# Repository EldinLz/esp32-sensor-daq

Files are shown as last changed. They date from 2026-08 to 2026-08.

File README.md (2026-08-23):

# ESP32 Sensor Data Acquisition Board

A custom two-layer PCB and Arduino firmware project for collecting ambient-light, temperature, humidity, and pressure data with an ESP32-C3.

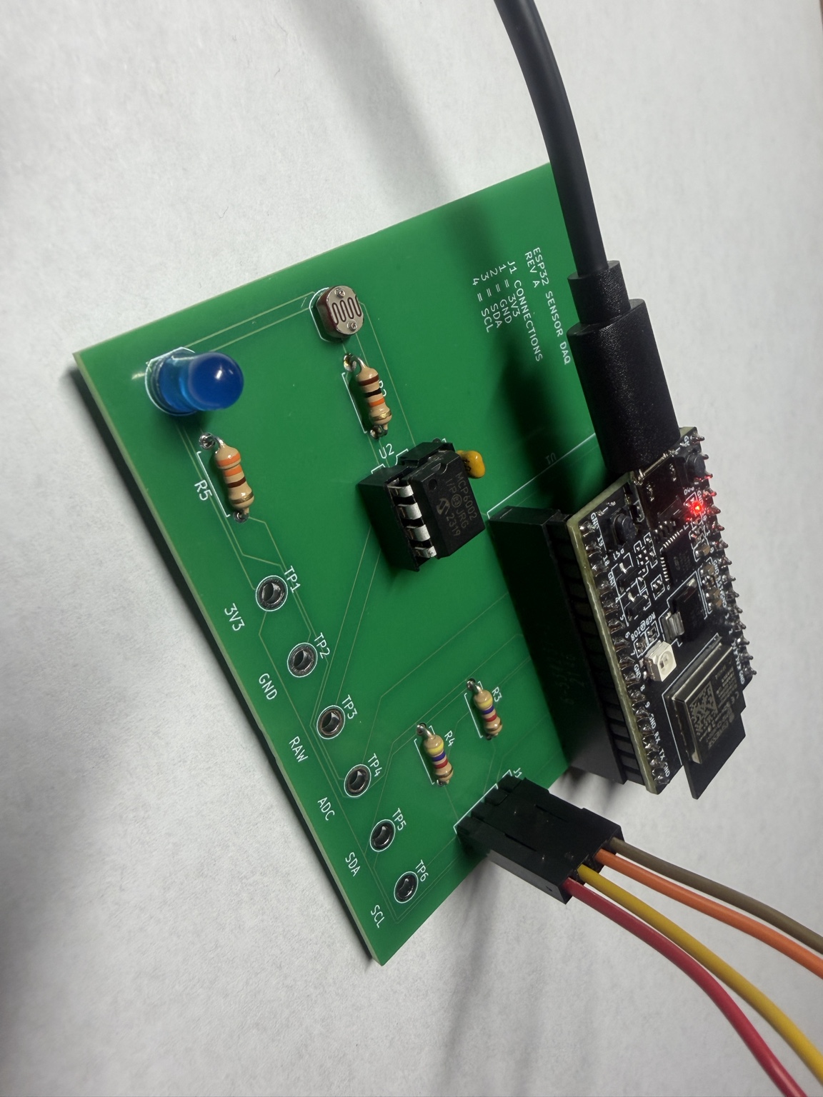
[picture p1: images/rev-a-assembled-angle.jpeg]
Assembled Rev A ESP32 sensor data-acquisition PCB


> **Project status:** Rev A was hand-assembled, programmed, and hardware-validated on 2026-08-22. The ESP32-C3 streams serial CSV data, the BME280 is detected over I2C, and the MCP6002-buffered light channel responds from covered to bright-light conditions. Long-duration logging and calibrated light measurement have not been completed.

## Overview

This project combines a custom KiCad carrier board with an ESP32-C3 DevKitM-1. A photoresistor signal is conditioned by an MCP6002 op-amp and sampled by the ESP32 ADC, while a BME280 breakout provides environmental data over I2C. Six labeled test points expose the primary power and signal nets for structured bring-up and debugging.

```mermaid
flowchart LR
    LDR["Photoresistor divider"] --> OP["MCP6002 buffer"]
    OP --> ADC["ESP32-C3 GPIO0 / ADC"]
    BME["BME280 temperature, humidity, pressure"] -->|"I2C: GPIO4 SDA, GPIO5 SCL"| ESP["ESP32-C3"]
    ADC --> ESP
    ESP --> LED["Status LED on GPIO7"]
    ESP --> USB["CSV data over USB serial"]
```

## Finished hardware

The Rev A PCB was assembled by hand with the ESP32-C3 in removable socket headers and the BME280 connected through the labeled J1 I2C header.

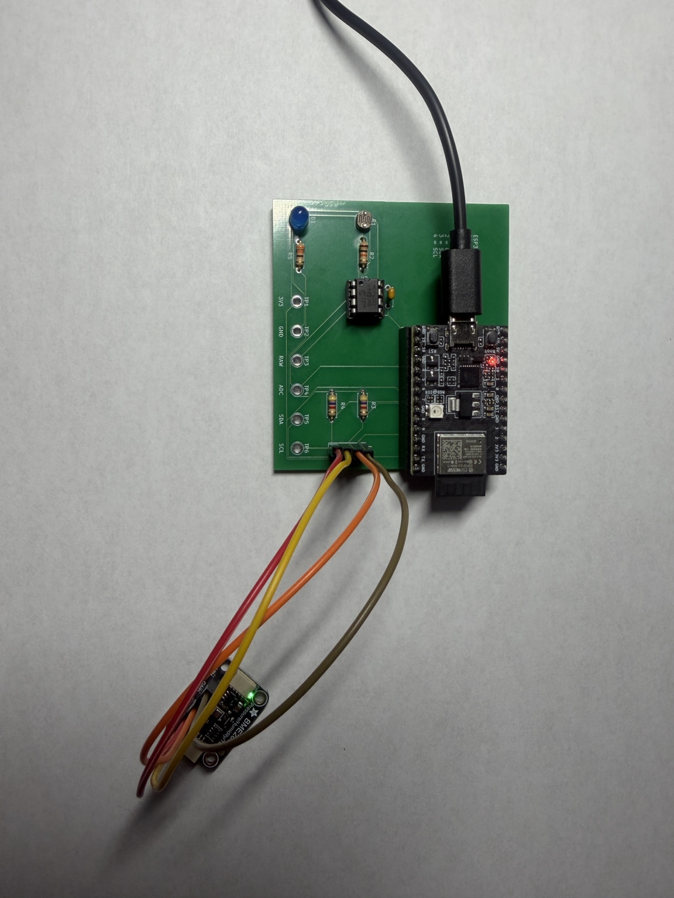
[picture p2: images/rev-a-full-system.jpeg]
Top-down view of the assembled PCB and connected BME280 breakout


## Key features

- ESP32-C3 DevKitM-1 controller on removable 1x15 sockets
- BME280 interface with 4.7 kOhm I2C pull-up resistors
- Photoresistor voltage divider buffered by an MCP6002 op-amp
- 100 nF local decoupling capacitor for the analog section
- Status LED with a 330 Ohm current-limiting resistor
- Six labeled test points: 3V3, GND, raw light signal, buffered ADC signal, SDA, and SCL
- CSV serial output suitable for logging or plotting
- Through-hole construction for accessible hand assembly and rework

## Pin map

| Function | ESP32-C3 pin | PCB test point or connector |
|---|---:|---|
| Light sensor ADC | GPIO0 | TP4 `ADC` |
| I2C SDA | GPIO4 | TP5 `SDA`, J1 pin 3 |
| I2C SCL | GPIO5 | TP6 `SCL`, J1 pin 4 |
| Status LED | GPIO7 | D1 through R5 |
| 3.3 V | 3V3 | TP1, J1 pin 1 |
| Ground | GND | TP2, J1 pin 2 |
| Raw light-divider signal | - | TP3 `RAW` |

## Firmware

The Arduino firmware:

1. Initializes the ESP32 ADC and the BME280 at address `0x77`, then tries `0x76` as a fallback.
2. Samples the buffered light-sensor signal once per second.
3. Reads temperature, humidity, and pressure when the BME280 is available.
4. Emits one CSV row per second at 115200 baud.

Measured Rev A serial output:

```text
BME280 detected
time_ms,light_raw,light_percent,temperature_C,humidity_percent,pressure_hPa
628,2058,50.3,25.70,47.22,1009.73
```

### Build environment

- Arduino IDE 2.3.10
- `esp32` board package by Espressif Systems 3.3.11
- Board target: `ESP32C3 Dev Module`
- Adafruit BME280 Library 2.3.0 and its installed dependencies

## Rev A hardware validation

These captured values demonstrate end-to-end operation; they are not calibration data.

| Check | Result | Captured evidence |
|---|---|---|
| Post-assembly power-off check | Pass | No 3V3-to-GND short was found. |
| 3.3 V operation | Pass | The assembled board powered and ran from the ESP32-C3 3.3 V rail. |
| Firmware and serial output | Pass | Firmware uploaded successfully and produced one 115200-baud CSV row per second. |
| BME280 I2C sensing | Pass | Serial Monitor reported `BME280 detected`; observed readings were about 25.2-26.0 C, 47-49% RH, and 1009.7-1009.9 hPa. |
| Light channel - covered | Pass | `light_raw` approximately 247-265; `light_percent` approximately 6.0-6.5%. |
| Light channel - room light | Pass | `light_raw` approximately 1887-2134; `light_percent` approximately 46.1-52.1%. |
| Light channel - flashlight | Pass | `light_raw` = 4095; `light_percent` = 100.0%. |
| Status LED | Pass | A brief firmware-driven activity blink was observed. |

`light_percent` is the 12-bit ADC reading normalized to full scale; it is not a calibrated lux measurement. The light tests validate the complete photoresistor-divider, MCP6002-buffer, ADC, firmware, and serial-output path, but do not independently characterize the op-amp transfer function.

See [VALIDATION.md](docs/VALIDATION.md) for the full validation record and [TEST_PLAN.md](docs/TEST_PLAN.md) for the staged bring-up procedure.

## Repository structure

```text
.
├── fabrication/  Final Gerber and drill archive used for PCB ordering
├── firmware/     Arduino sketch folder and firmware source
├── hardware/     KiCad schematic, PCB, and project files
├── images/       KiCad renders and finished Rev A build photos
└── docs/         BOM, validation record, test plan, and resume notes
```

## Design and validation status

- KiCad schematic ERC: 0 errors and 0 warnings
- KiCad PCB Editor DRC: 0 errors; one expected footprint/library mismatch warning after the ESP32 socket-pad customization
- Unrouted connections: 0
- Gerber and drill archive generated; PCB fabrication and delivery complete
- Rev A assembly, soldering, post-assembly short check, firmware upload, and serial output: complete
- BME280 I2C sensing and end-to-end light-channel response: hardware-validated

## Optional follow-on characterization

- Run and archive a one-hour serial logging test
- Measure TP3 (`RAW`) and TP4 (`ADC`) simultaneously to quantify buffer tracking
- Calibrate the light channel against a lux reference if absolute illumination is required

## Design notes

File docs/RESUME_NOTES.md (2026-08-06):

# Resume and Interview Notes

## Current truthful project summary

Designed a two-layer ESP32-C3 sensor data-acquisition PCB in KiCad, integrating a buffered photoresistor analog front end, BME280 I2C interface, status LED, decoupling, and six labeled test points. Routed and prepared fabrication files, ordered prototype PCBs, and wrote compile-verified Arduino C++ firmware that exports timestamped environmental data as CSV. Physical bring-up is pending hardware arrival and assembly.

## Resume bullet — current stage

- Designed and routed a 65.5 mm × 73.5 mm two-layer ESP32-C3 sensor data-acquisition PCB in KiCad, integrating an MCP6002-buffered light sensor, BME280 I2C interface, status LED, and six debug test points; generated production Gerbers and compile-verified Arduino C++ firmware for CSV telemetry.

## Resume bullet — use only after successful hardware validation

- Designed, assembled, and validated a custom ESP32-C3 environmental data-acquisition PCB, integrating analog light sensing and BME280 temperature/humidity/pressure telemetry; developed Arduino C++ firmware and verified power, I2C, ADC, and serial logging through a structured test-point bring-up plan.

## Interview talking points

- Placement was organized by functional blocks: analog sensing, I2C interface, status indication, and accessible test points.
- The MCP6002 buffers the photoresistor divider so the ADC sees a low-impedance signal.
- The firmware handles both common BME280 I2C addresses and continues logging light data when the BME280 is unavailable.
- Test points were designed in from the start so power, raw analog, buffered analog, SDA, and SCL can be measured directly.
- The project status is documented explicitly so compile checks are not confused with physical validation.

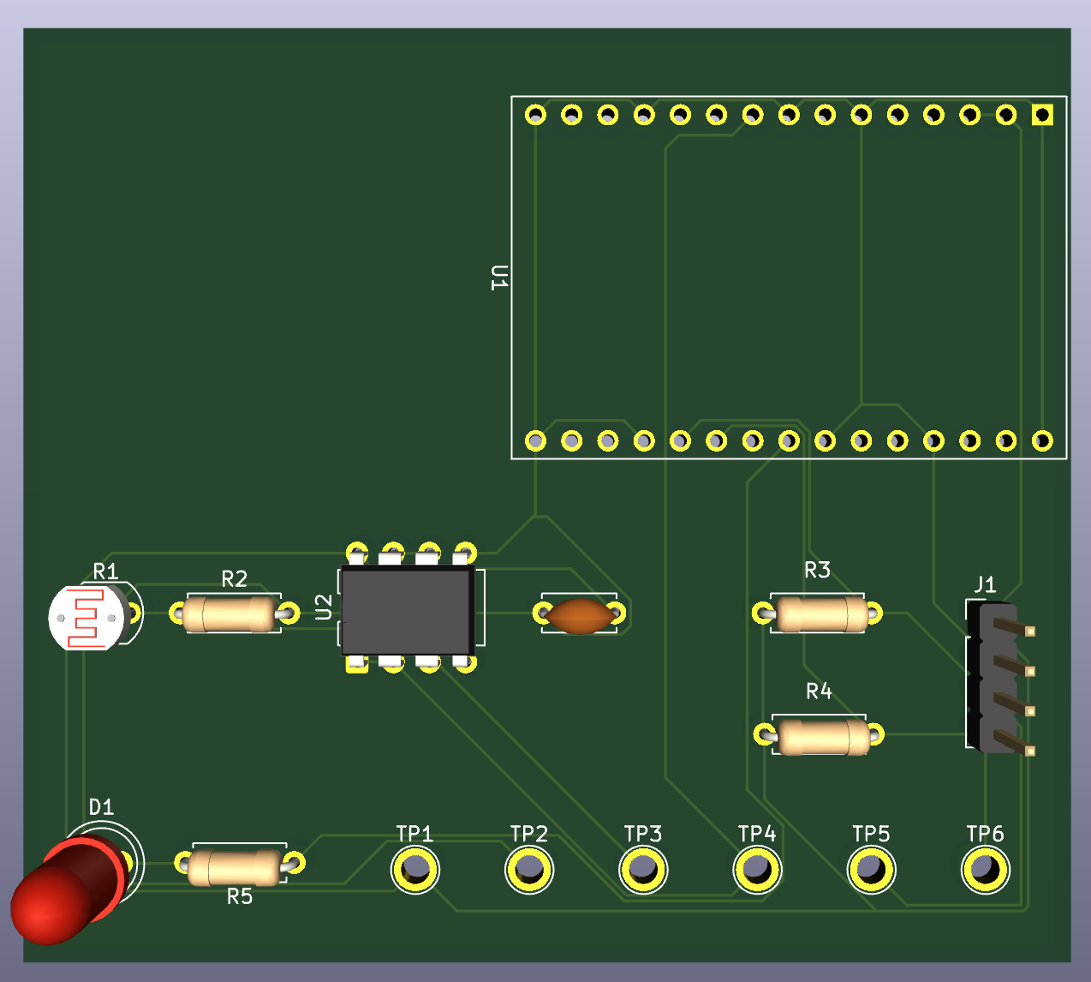
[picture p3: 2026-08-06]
images/pcb-3d-top.png

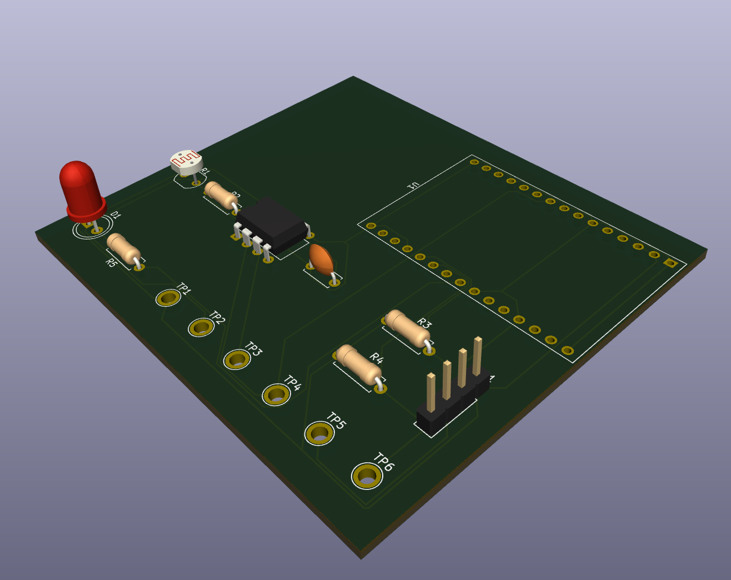
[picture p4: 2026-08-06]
images/pcb-3d-perspective.png

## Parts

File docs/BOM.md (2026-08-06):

# Bill of Materials

Quantities below are for one assembled board. Exact supplier stock can change; verify the footprint, lead pitch, and voltage rating before substituting a part.

| Ref. | Qty. | Component | Value / selected part | PCB footprint or interface |
|---|---:|---|---|---|
| U1 | 1 | ESP32-C3 development board | ESP32-C3 DevKitM-1 | Two 1x15, 2.54 mm socket rows |
| U2 | 1 | Dual rail-to-rail op-amp | MCP6002-I/P | DIP-8, 7.62 mm row spacing |
| — | 1 | DIP socket | 8-position | DIP-8 |
| R1 | 1 | CdS photoresistor | 5 mm class | 3.4 mm lead pitch footprint |
| R2 | 1 | Resistor | 10 kΩ, 1/4 W | Axial, 7.62 mm pitch |
| R3, R4 | 2 | I2C pull-up resistors | 4.7 kΩ, 1/4 W | Axial, 7.62 mm pitch |
| R5 | 1 | LED resistor | 330 Ω, 1/4 W | Axial, 7.62 mm pitch |
| C1 | 1 | Ceramic capacitor | 100 nF | Through-hole disc, 5.00 mm pitch |
| D1 | 1 | Status LED | 5 mm LED | 2.54 mm pitch |
| J1 | 1 | BME280 connector | 1x4 vertical pin header | 2.54 mm pitch |
| — | 1 | BME280 breakout | Adafruit BME280 I2C/SPI breakout | Connected to J1 over 3V3, GND, SDA, SCL |
| — | 2 | ESP32 socket strips | 1x15 female receptacle | 2.54 mm pitch |

## Test points

TP1 through TP6 are plated through-holes and do not require a separate component. Optional loop or turret test points may be installed if desired.

| Test point | Net |
|---|---|
| TP1 | 3V3 |
| TP2 | GND |
| TP3 | LIGHT_RAW |
| TP4 | LIGHT_ADC |
| TP5 | I2C_SDA |
| TP6 | I2C_SCL |

## Assembly supplies

- Solder and flux
- Female-to-female jumper wires for the BME280 breakout
- USB data cable for ESP32 programming
- Multimeter with continuity and DC-voltage modes

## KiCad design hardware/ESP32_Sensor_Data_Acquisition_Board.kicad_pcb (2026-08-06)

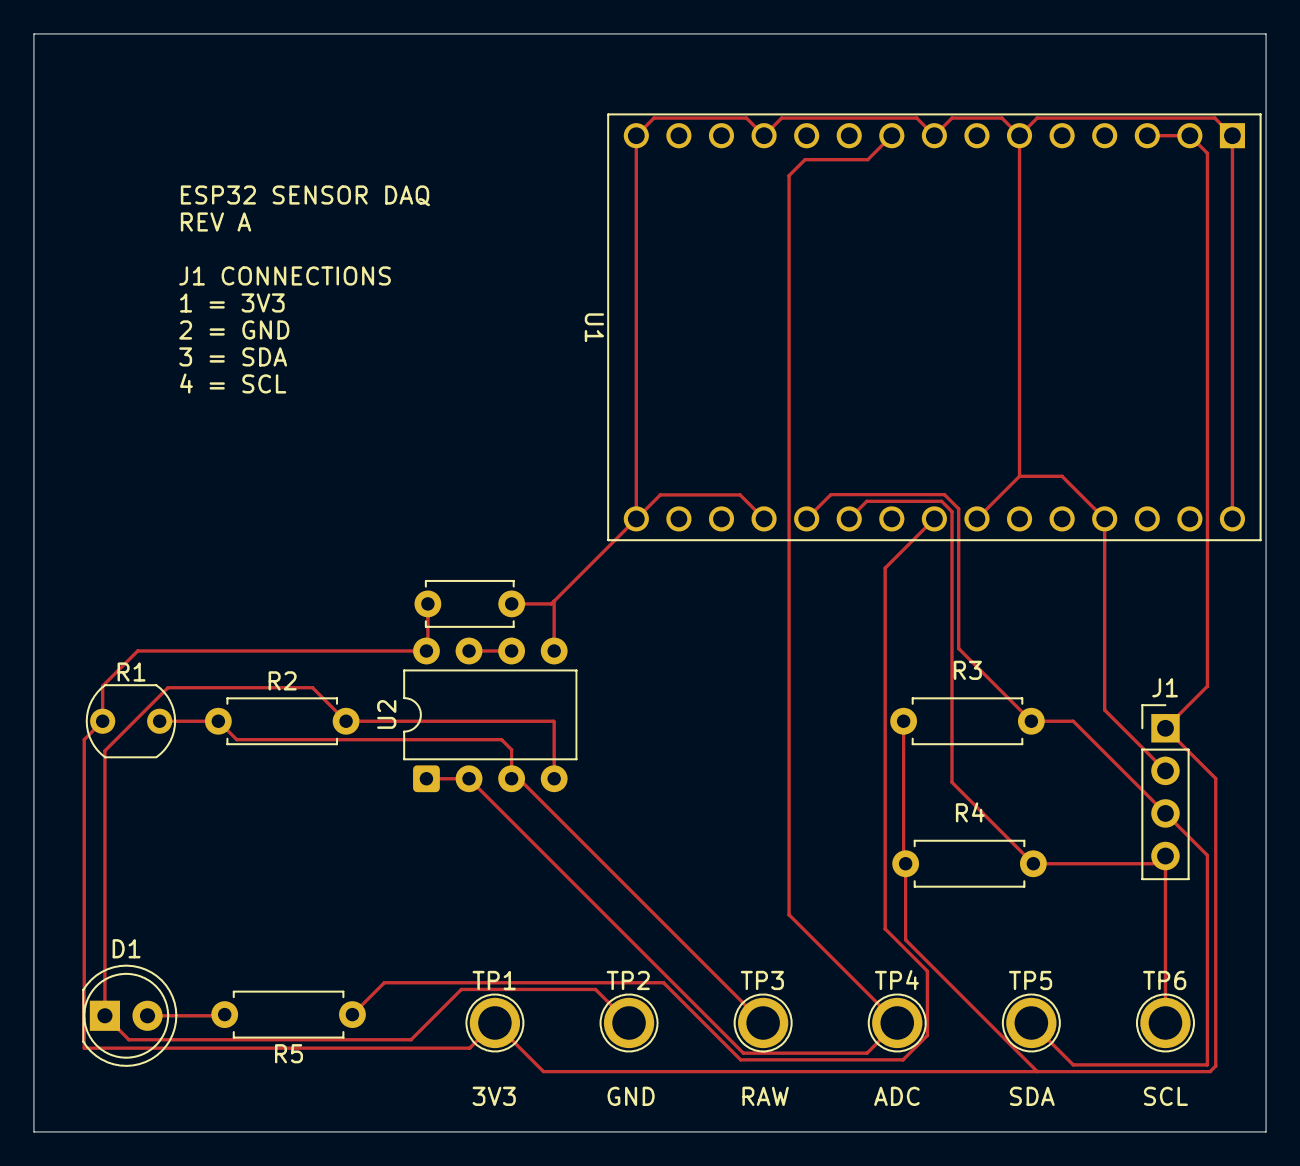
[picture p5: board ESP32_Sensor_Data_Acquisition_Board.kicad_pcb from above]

Board: 2 copper layers, 73.5 x 65.5 mm, 16 parts (0 on the bottom side), 9 nets.

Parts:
C1: 100nF; C_Disc_D5.0mm_W2.5mm_P5.00mm
D1: LED; LED_D5.0mm
J1: BME280; PinHeader_1x04_P2.54mm_Vertical
R1: R_Photo; R_LDR_5.1x4.3mm_P3.4mm_Vertical
R2: 10k; R_Axial_DIN0207_L6.3mm_D2.5mm_P7.62mm_Horizontal
R3, R4: 4.7k; R_Axial_DIN0207_L6.3mm_D2.5mm_P7.62mm_Horizontal
R5: 330; R_Axial_DIN0207_L6.3mm_D2.5mm_P7.62mm_Horizontal
TP1, TP2, TP3, TP4, TP5, TP6: TestPoint; TestPoint_Plated_Hole_D2.0mm
U1: ESP32-C3-DevKitM-1
U2: MCP6002-xP; DIP-8_W7.62mm

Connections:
+3V3: C1.1, J1.1, R1.1, R3.1, R4.1, TP1.1 (1_1), U1.2 (3V3), U1.3 (3V3), U2.8 (V+)
/I2C_SCL: J1.4, R4.2, TP6.1 (1_1), U1.21 (IO5)
/I2C_SDA: J1.3, R3.2, TP5.1 (1_1), U1.20 (IO4)
/LIGHT_ADC: TP4.1 (1_1), U1.9 (IO0), U2.1, U2.2 (-)
/LIGHT_RAW: R1.2, R2.1, TP3.1 (1_1), U2.3 (+)
/STATUS_LED: R5.1, U1.23 (IO7)
GND: C1.2, D1.1 (K), J1.2, R2.2, TP2.1 (1_1), U1.1 (GND), U1.6 (GND), U1.8 (GND), U1.12 (GND), U1.15 (GND), U1.16 (GND), U1.19 (GND), U1.24 (GND), U1.27 (GND), U1.30 (GND), U2.4 (V-), U2.5 (+)
unnamed: D1.2 (A), R5.2
unnamed: U2.6 (-), U2.7

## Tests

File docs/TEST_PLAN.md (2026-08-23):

# Assembly and Hardware Test Plan

This plan is intentionally staged so that a soldering or power fault can be found before expensive modules are inserted.

## 1. Bare-board inspection

- Confirm the board outline is intact and flat.
- Inspect every plated hole for complete copper plating.
- Confirm the U1 square pad identifies pin 1.
- Confirm the J1 silkscreen mapping: pin 1 = 3V3, pin 2 = GND, pin 3 = SDA, pin 4 = SCL.
- Check for scratches, solder-mask damage, or copper bridges.

## 2. Power-off electrical checks

Use continuity or resistance mode before inserting U1, U2, or the BME280.

- TP1 (3V3) to TP2 (GND) must not be a short.
- J1 pin 1 must connect to TP1.
- J1 pin 2 must connect to TP2.
- J1 pin 3 must connect to TP5.
- J1 pin 4 must connect to TP6.
- Verify the LED polarity marking and the DIP-8 socket notch orientation.

Stop and correct the board if the 3V3-to-GND measurement is near zero ohms.

## 3. Assembly order

1. Solder the resistors and C1.
2. Solder the DIP-8 socket; leave the MCP6002 out initially.
3. Solder the photoresistor, LED, and J1 header.
4. Solder both 1x15 ESP32 socket rows using the ESP32 module only as a temporary alignment guide.
5. Clean and inspect every joint.
6. Repeat the 3V3-to-GND short check.
7. Insert the MCP6002 with its pin-1 notch aligned to the footprint.
8. Insert the ESP32-C3 in the correct orientation.

## 4. First power-up

- Disconnect the BME280 for the first power-up.
- Connect the ESP32 by USB through a current-limited USB source when available.
- Measure TP1 relative to TP2; expected value is approximately 3.3 V.
- Disconnect power immediately if a component becomes hot, the voltage collapses, or excessive current is observed.

## 5. Firmware upload

1. Open `firmware/ESP32_Sensor_DAQ_Firmware/ESP32_Sensor_DAQ_Firmware.ino` in Arduino IDE.
2. Select `ESP32C3 Dev Module` and the connected serial port.
3. Compile and upload.
4. Open Serial Monitor at 115200 baud.
5. Confirm the CSV header appears and one data row is emitted each second.

With the BME280 disconnected, `NA,NA,NA` is expected for its three fields.

## 6. BME280 test

- Power off before connecting the breakout to J1.
- Connect 3V3, GND, SDA, and SCL exactly as labeled.
- Reapply power and confirm `BME280 detected` in Serial Monitor.
- Confirm temperature, humidity, and pressure values are plausible and stable.
- The firmware tries I2C address `0x77`, then `0x76`.

## 7. Light channel test

- Record TP3 (`RAW`) and TP4 (`ADC`) voltages under normal room light.
- Cover the photoresistor and confirm both values change.
- Illuminate the photoresistor and confirm both values change in the opposite direction.
- Confirm `light_raw` remains within 0-4095 and changes with illumination.
- Compare TP3 and TP4 to confirm the op-amp buffer follows the raw signal without obvious clipping.

## 8. Stability test

- Log serial output for at least one hour.
- Check for resets, malformed CSV rows, missing BME280 readings, or values stuck at a rail.
- Save a sample log and a plot for the portfolio README after successful testing.

## Test record

| Item | Result | Measurement / notes |
|---|---|---|
| Bare-board inspection | Pass | No obvious fabrication defects found. |
| 3V3-to-GND short check | Pass | No short found before or after Rev A assembly. |
| Known power/connector net continuity | Pass | Expected continuity confirmed on known power and connector nets. |
| TP1 / 3.3 V operation | Pass | The assembled board powered and ran from the ESP32-C3 3.3 V rail. |
| Firmware upload | Pass | Upload completed, the flashed image hash was verified, and the ESP32-C3 reset into the application. |
| Status LED | Pass | Brief firmware-driven activity blink observed. |
| BME280 detected | Pass | Serial Monitor reported `BME280 detected`. |
| Temperature plausible | Pass | Approximately 25.2-26.0 C during bring-up. |
| Humidity plausible | Pass | Approximately 47-49% RH during bring-up. |
| Pressure plausible | Pass | Approximately 1009.7-1009.9 hPa during bring-up. |
| End-to-end light response | Pass | Approximately 6% covered, 46-52% in room light, and 100% under a flashlight. Percentages are normalized ADC full scale, not lux. |
| Direct TP3-to-TP4 transfer measurement | Pending | The complete light channel works, but standalone buffer tracking has not been quantified. |
| One-hour logging test | Pending | Long-duration stability logging has not been completed. |

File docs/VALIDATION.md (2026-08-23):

# Validation Record

Rev A functional hardware bring-up was completed on 2026-08-22.

## Completed checks

| Check | Result | Evidence / notes |
|---|---|---|
| Schematic electrical-rules check | Pass | KiCad 10.0.4 CLI reported 0 errors and 0 warnings on 2026-08-05. |
| PCB design-rules check | Pass with one expected warning | KiCad PCB Editor reported 0 errors and 1 footprint/library mismatch warning. The warning is expected because the ESP32 socket pad sizes were customized in the board copy. |
| Schematic/PCB parity | Pass | KiCad PCB Editor reported 0 parity issues. |
| Routed connections | Pass | KiCad status and DRC reported 0 unconnected items. |
| Manufacturing archive | Complete | Final two-layer Gerber and drill archive is stored in `fabrication/`. |
| Manufacturer preview | Reviewed | Top/bottom copper, solder mask, silkscreen, board outline, and drill layers were reviewed before ordering. |
| PCB fabrication and delivery | Complete | The manufactured PCBs arrived and Rev A was selected for assembly. |
| Bare-board visual inspection | Pass | No obvious fabrication defects were found. |
| Initial power-off continuity checks | Pass | No 3V3-to-GND short was found, and expected continuity was confirmed on known power and connector nets. |
| Physical assembly | Complete | Rev A through-hole components, sockets, header, and supporting circuitry were hand-soldered and inspected. |
| Post-assembly power-off check | Pass | No 3V3-to-GND short was found before powered bring-up. |
| 3.3 V operation | Pass | The assembled board powered and ran from the ESP32-C3 3.3 V rail. |
| Firmware compilation and upload | Pass | Arduino IDE 2.3.10, ESP32 core 3.3.11, target `ESP32C3 Dev Module`, Adafruit BME280 Library 2.3.0. Upload completed and the flashed image hash was verified. |
| Serial CSV output | Pass | Firmware emitted the expected header and one data row per second at 115200 baud. |
| Status LED | Pass | A brief firmware-driven activity blink was observed. |
| BME280 discovery | Pass | Serial Monitor reported `BME280 detected` over I2C. |
| BME280 sensor plausibility | Pass | Captured readings were approximately 25.2-26.0 C, 47-49% RH, and 1009.7-1009.9 hPa during bring-up. |
| End-to-end light-channel response | Pass | Covered: approximately 247-265 counts (6.0-6.5%); room light: approximately 1887-2134 counts (46.1-52.1%); flashlight: 4095 counts (100.0%). |

## Scope and remaining characterization

- `light_percent` is ADC full-scale percentage, not calibrated lux.
- The light response validates the complete photoresistor-divider, MCP6002-buffer, ESP32 ADC, firmware, and serial-output path. TP3-to-TP4 transfer accuracy has not been independently measured.
- Temperature, humidity, and pressure were checked for plausible live response but were not calibrated against reference instruments.
- The planned one-hour serial logging stability test has not been completed.

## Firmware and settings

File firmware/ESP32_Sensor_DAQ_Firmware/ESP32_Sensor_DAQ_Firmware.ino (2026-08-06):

#include <Wire.h>
#include <Adafruit_Sensor.h>
#include <Adafruit_BME280.h>

// Pin connections from your KiCad PCB
const int LIGHT_SENSOR_PIN = 0;
const int SDA_PIN = 4;
const int SCL_PIN = 5;
const int STATUS_LED_PIN = 7;

Adafruit_BME280 bme;
bool bmeAvailable = false;

void setup() {
  Serial.begin(115200);
  delay(500);

  pinMode(STATUS_LED_PIN, OUTPUT);
  digitalWrite(STATUS_LED_PIN, LOW);

  analogReadResolution(12);
  Wire.begin(SDA_PIN, SCL_PIN);

  // Adafruit BME280 normally uses 0x77.
  // Try 0x76 as a backup.
  bmeAvailable = bme.begin(0x77, &Wire);

  if (!bmeAvailable) {
    bmeAvailable = bme.begin(0x76, &Wire);
  }

  if (bmeAvailable) {
    Serial.println("BME280 detected");
  } else {
    Serial.println("BME280 not detected");
  }

  Serial.println(
    "time_ms,light_raw,light_percent,"
    "temperature_C,humidity_percent,pressure_hPa"
  );
}

void loop() {
  digitalWrite(STATUS_LED_PIN, HIGH);

  int lightRaw = analogRead(LIGHT_SENSOR_PIN);
  float lightPercent = (lightRaw / 4095.0) * 100.0;

  Serial.print(millis());
  Serial.print(",");
  Serial.print(lightRaw);
  Serial.print(",");
  Serial.print(lightPercent, 1);
  Serial.print(",");

  if (bmeAvailable) {
    Serial.print(bme.readTemperature(), 2);
    Serial.print(",");
    Serial.print(bme.readHumidity(), 2);
    Serial.print(",");
    Serial.println(bme.readPressure() / 100.0, 2);
  } else {
    Serial.println("NA,NA,NA");
  }

  digitalWrite(STATUS_LED_PIN, LOW);
  delay(1000);
}

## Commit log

2026-08-06 Publish ESP32 sensor DAQ portfolio project
    [ESP32_Sensor_Data_Acquisition_Board.kicad_pcb, ESP32_Sensor_Data_Acquisition_Board.kicad_sch]
2026-08-20 docs: record bare-board validation
2026-10-21 docs: add readable Rev A schematic
2026-10-21 docs: add WindBorne PCB challenge write-up
2026-10-21 docs: simplify PCB challenge description
